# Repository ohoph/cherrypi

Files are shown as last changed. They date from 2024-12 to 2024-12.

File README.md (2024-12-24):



# cherrypi

Raspberry Pi Zero 2 W based Portable Chess Computer





# Cherrypi - über Kirschkuchen und Schachcomputer

Dieses Repository dokumentiert den Aufbau meines selbstgebauten Schachcomputers – ein persönliches Projekt, das von der Idee bis zur Umsetzung eine Reise voller Höhen und Tiefen war. Der Computer sollte ein Weihnachtsgeschenk sein, das nicht nur funktional, sondern auch emotional besonders ist. Obwohl er heute nicht funktionsfähig ist, bedeutet mir dieses Projekt eine Menge. Es war eine Reise mit vielen Höhen und Tiefen, ich habe sooo viel gelernt und hoffe darauf, dass dieses Projekt eines Tages (bald) von allen nachgebaut werden kann, die sich ein ähnliches Projekt wünschen. 

IMG_8A8BB41F64B1-1

---

## 🛠️ **Funktionalität**

Der Cherrypi-Schachcomputer bietet:

1. **Eigenständige Schachfunktion:**
   - Nutzt **Stockfish** als Schach-Engine. Spielt auf etwa 2500er ELO. 
   - Steuere das Spiel mit einer 16-Tasten-Matrix (ähnlich einem tragbaren Brett).
   - Zeigt Spielinformationen auf einem **OLED-Display** an.

2. **Portabilität:**
   - Dank eines **UPS-Moduls** (mit Akku) und eines **Ein/Aus-Schiebeschalters** kann der Computer überall verwendet werden.

3. **Software-Integration:**
   - Automatischer Start in das Schachprogramm direkt beim Hochfahren.
   - Alle Funktionen laufen eigenständig – ohne Internetverbindung.

4. **Benutzerfreundliches Gehäuse:**
   - Ein 3D-gedrucktes Gehäuse schützt die Hardware.
   - Magnetverschluss für einfachen Zugriff auf die Elektronik.
   - 3D-gedruckte Keycaps für ein individuelles Schach-Feeling.

---
## 🎮 **Spielanleitung**

### **Tastenbelegung**
Die 16-Tasten-Matrix ist wie folgt organisiert:

| Taste (S1-S16) | Funktionalität | Beschreibung |
|---|---|---|
| S1 | A/1 | Spalte A oder Reihe 1 |
| S2 | B/2 | Spalte A oder Reihe 1 |
| S3 | C/3 | Spalte A oder Reihe 1 |
| S4 | D/4 | Spalte A oder Reihe 1 |
| S5 | E/5 | Spalte A oder Reihe 1 |
| S6 | F/6 | Spalte A oder Reihe 1 |
| S7 | G/7 | Spalte A oder Reihe 1 |
| S8 | H/8 | Spalte A oder Reihe 1 |
| S9 | Dame | Bauernumwandlung in Dame |
| S10 | Turm | Bauernumwandlung in Turm |
| S11 | Läufer | Bauernumwandlung in Läufer |
| S12 | Springer | Bauernumwandlung in Springer |
| S13 | Surrender | Beendet Spiel durch Aufgabe |
| S14 | Clear | Löscht gesamte Eingabe |
| S15 | Delete | Löscht letzte Ziffer von Eingabe |
| S16 | Go | Bestätigt Eingabe |

### **Züge eingeben**
- Um einen Zug einzugeben, drücke **nacheinander zwei Felder**:
  - Das erste Feld ist die Startposition des Steins.
  - Das zweite Feld ist die Zielposition des Steins.
  - Beispiel: Um von `E2` nach `E4` zu ziehen, drücke die Tasten 5,2,5,4 (e2e4) und bestätige den Zug mit "Go". 

### **Sonderfunktionen**
- **Bauernumwandlung:**
  - Wird ein Bauer in die letzte Reihe bewegt, erscheint auf dem Display die Aufforderung zur Umwandlung.
  - Wähle mit den Tasten `9`, `10`, `11`, `12` die gewünschte Figur:
    - `9`: Königin
    - `10`: Turm
    - `11`: Läufer
    - `12`: Springer

- **Rochade:**
  - Gib den Zug des Königs an. Das System erkennt automatisch die Rochade, sofern legal.

- **Zug zurücknehmen:**
  - Halte die Taste `14` gedrückt, um den letzten Zug zurückzunehmen.

- **Neues Spiel starten:**
  - Halte `13` gedrückt, um aufzugeben und eine neue Partie zu beginnen.

### **Display-Anzeige**

- Das OLED-Display zeigt:
  - Den aktuellen Zug.
  - Die letzten Züge.
  - Hinweise wie "Press any key to start" oder Fehler bei illegalen Zügen.

## 🔧 **Zusammenbau**

### **Benötigte Komponenten**
- **Raspberry Pi Zero W** (ohne Headerpins).
- **1,3-Zoll-OLED-Display** (I2C, 128x64 Pixel).
- **16-Tasten-Matrix**.
- **3D-gedrucktes Gehäuse** (STLs sind in diesem Repository verfügbar!).
- **3D-gedruckte Keycaps für die Tasten-Matrix** (Wird diesem Repository als STL beigefügt, sobald die finalen Designs fertig sind)
- **Magnete** für den Verschlussmechanismus.
- **Lötstation**, Lötzinn, Entlötpumpe und Multimeter.

### **Software**
- Raspberry Pi OS Lite (32-Bit).
- Python-Skripte für das Schachprogramm, das OLED-Display und die Tastatureingabe.
- Systemd-Dienste für das automatische Starten von Programmen und das Überwachen des UPS-Schalters.

---

## 💡 **Schritte zum Zusammenbau**

### **1. Hardware vorbereiten**
- **OLED-Display:** I2C-Verbindungen verlöten und testen.
- **Tastaturmatrix:** Verlöten und mit GPIO-Pins verbinden.
- **Raspberry Pi:** Headerpins entfernen (falls vorhanden) und alle Verbindungen sauber verlöten.
- **UPS-Modul:** Mit dem Pi verbinden und den Schalter für Ein/Aus konfigurieren.

### 2. Softwareanforderungen
1. **Raspberry Pi OS** (aktuellste Version)
2. **Python 3**
3. Bibliotheken:
   - `RPi.GPIO`
   - `luma.oled`
   - `Pillow`
   - `python-chess`
   - `stockfish`
4. **I2C-Tools** zur Aktivierung und Testen des I2C-Busses.

### Hardware und Komponentenliste
| **Komponente** | **Anzahl** | **Beschreibung** |
|---|---|---|
| Raspberry Pi Zero 2 W | 1 | Mini-Computer zur Steuerung |
| 1.3 Zoll OLED Display (SH1106, I2C) | 1 | Display zur Anzeige der Schachzüge |
| 4x4 Button-Matrix | 1 | Eingabegerät für Schachzüge |
| LiPo-Akku 3.7V (1000mAh) | 1 | Stromversorgung für den Raspberry Pi |
| Waveshare UPS HAT für Raspberry Pi Zero | 1 | HAT-Modul zur Akkuverwaltung und Stromversorgung|
| Micro-SD-Karte (mind. 8GB) | 1 | Speicherkarte für Raspberry Pi OS und Code |

---

## Wiring Guide 

Bildschirmfoto 2024-12-16 um 10 53 50

### Button-Matrix Verkabelung
| **Matrix-Pin** | **Raspberry Pi GPIO (BCM)** | **Physischer Pin** | **Beschreibung** |
|---|---|---|---|
| **1** | GPIO 25 | Pin 22 | Zeile 1 |
| **2** | GPIO 23 | Pin 16 | Zeile 2 |
| **3** | GPIO 24 | Pin 18 | Zeile 3 |
| **4** | GPIO 18 | Pin 12 | Zeile 4 |
| **5** | GPIO 27 | Pin 13 | Spalte 1 |
| **6** | GPIO 22 | Pin 15 | Spalte 2 |
| **7** | GPIO 17 | Pin 11 | Spalte 3 |
| **8** | GPIO 4 | Pin 7 | Spalte 4 |

### OLED-Display (SH1106) Verkabelung
| **OLED Pin** | **Raspberry Pi GPIO (BCM)** | **Physischer Pin** | **Beschreibung** |
|---|---|---|---|
| **VCC** | 3.3V | Pin 1 | Spannungsversorgung |
| **GND** | GND | Pin 9 | Masse |
| **SDA** | GPIO 2 (SDA) | Pin 3 | I2C-Datenleitung |
| **SCL** | GPIO 3 (SCL) | Pin 5 | I2C-Taktleitung | 

### Zusammenfassung der Pinbelegung
| **Funktion** | **Raspberry Pi GPIO (BCM)** | **Physischer Pin** |
|---|---|---|
| Button-Matrix Zeile 1 | GPIO 25 | Pin 22 |
| Button-Matrix Zeile 2 | GPIO 23 | Pin 16 |
| Button-Matrix Zeile 3 | GPIO 24 | Pin 18 |
| Button-Matrix Zeile 4 | GPIO 18 | Pin 12 |
| Button-Matrix Spalte 1| GPIO 27 | Pin 13 |
| Button-Matrix Spalte 2| GPIO 22 | Pin 15 |
| Button-Matrix Spalte 3| GPIO 17 | Pin 11 |
| Button-Matrix Spalte 4| GPIO 4 | Pin 7 |
| OLED VCC | 3.3V | Pin 1 |
| OLED GND | GND | Pin 9 |
| OLED SDA | GPIO 2 (SDA) | Pin 3 |
| OLED SCL | GPIO 3 (SCL) | Pin 5 |

### Hinweise für die Verkabelung
1. **Button-Matrix**: Die Reihen-Pins sind als **Eingänge** und die Spalten-Pins als **Ausgänge** konfiguriert.
2. **OLED-Display**: Verwendet das **I2C-Protokoll**; muss in der Raspberry Pi Konfiguration aktiviert entsprechend werden (`sudo raspi-config`).

### Bildergalerie



IMG_86837E7B299C-1

https://github.com/user-attachments/assets/6dfa8066-77cf-47a0-b1ef-a18c7b4af382

---

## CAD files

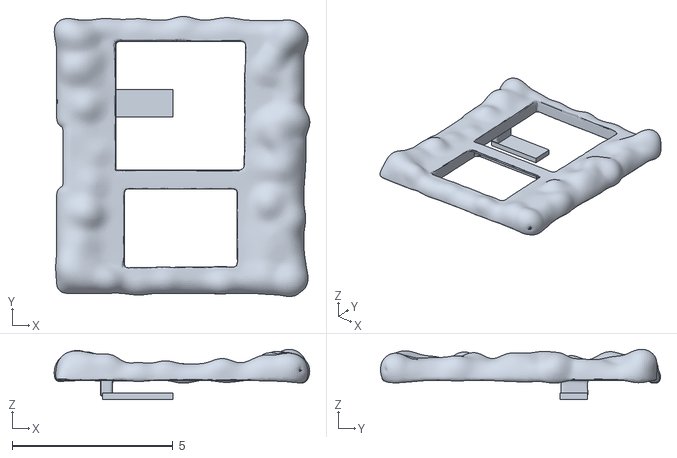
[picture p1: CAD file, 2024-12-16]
STLs/chesspbry_finalv1_top.stl
7.94 x 8.70 x 1.56

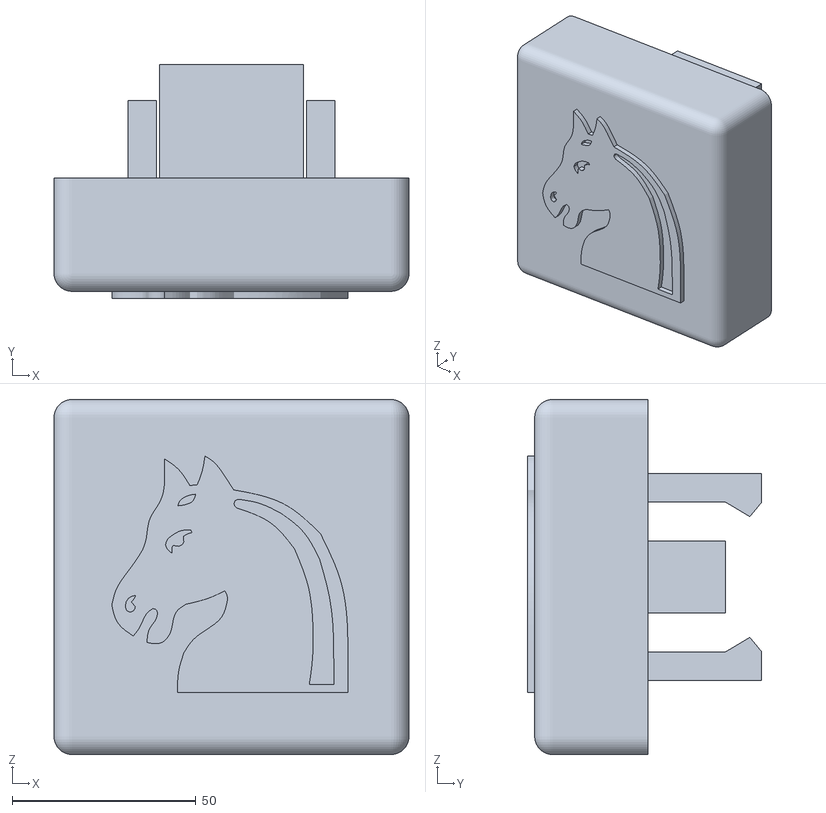
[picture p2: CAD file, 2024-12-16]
STLs/Keycap STLs/Springer-cap.stl
96.5 x 63.7 x 96.5

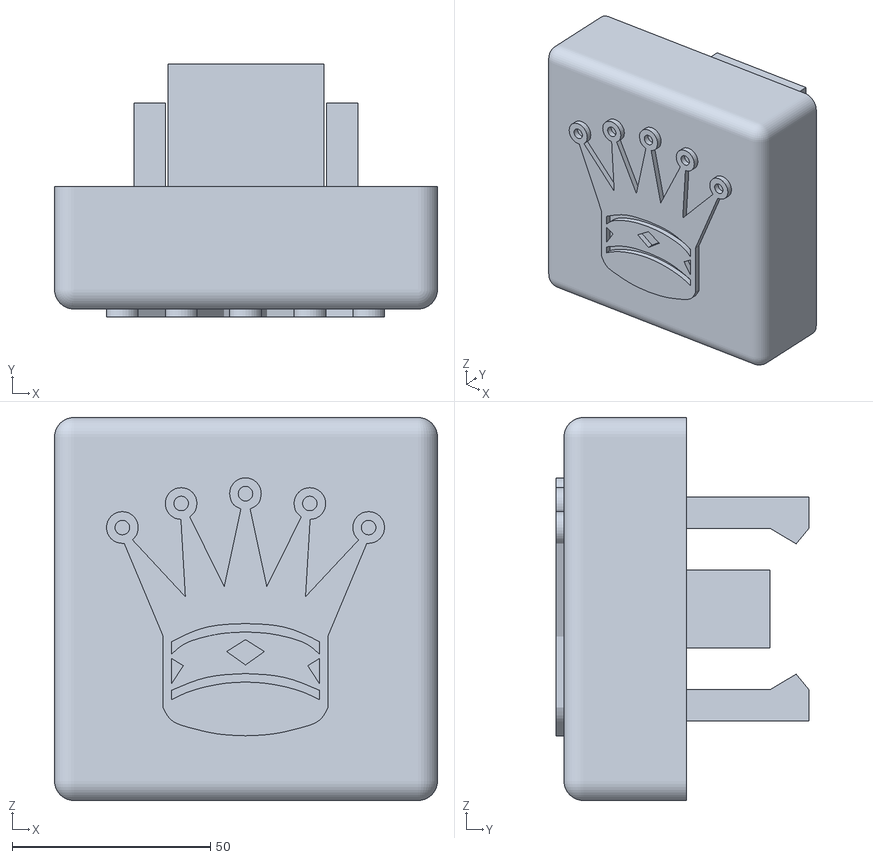
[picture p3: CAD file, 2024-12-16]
STLs/Keycap STLs/Königin.stl
96.5 x 63.7 x 96.5

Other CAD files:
STLs/Keycap STLs/Läufer-Cap.stl
STLs/Keycap STLs/Turm-cap.stl
STLs/Keycap STLs/B2-cap.stl
STLs/Keycap STLs/Go-cap.stl
STLs/Keycap STLs/C3-cap.stl
STLs/Keycap STLs/F6-cap.stl
STLs/Keycap STLs/G7-cap.stl
STLs/Keycap STLs/Correct-cap.stl
STLs/Keycap STLs/König-cap.stl
STLs/Keycap STLs/Cancel-cap.stl
STLs/Keycap STLs/A1-cap.stl
STLs/Keycap STLs/E5-cap.stl
STLs/Keycap STLs/H8-cap.stl
STLs/Keycap STLs/D4-cap.stl

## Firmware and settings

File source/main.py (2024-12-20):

import random
import RPi.GPIO as GPIO
import time
import chess
import chess.engine
from luma.core.interface.serial import i2c
from luma.oled.device import sh1106
from PIL import ImageDraw, ImageFont, Image


# GPIO-Setup für Buttons
class ButtonMatrix:
    def __init__(self):
        GPIO.setmode(GPIO.BCM)
        GPIO.setwarnings(False)
        self.buttonIDs = [[4, 3, 2, 1], [8, 7, 6, 5], [16, 15, 14, 13], [12, 11, 10, 9]]
        self.rowPins = [18, 23, 24, 25]
        self.columnPins = [21, 22, 17, 4]
        for row in self.rowPins:
            GPIO.setup(row, GPIO.IN, pull_up_down=GPIO.PUD_UP)
        for col in self.columnPins:
            GPIO.setup(col, GPIO.OUT)
            GPIO.output(col, GPIO.HIGH)

    def readButton(self):
        for j, colPin in enumerate(self.columnPins):
            GPIO.output(colPin, GPIO.LOW)  # Aktiviere Spalte
            for i, rowPin in enumerate(self.rowPins):
                if GPIO.input(rowPin) == GPIO.LOW:  # Wenn Zeile aktiviert wird
                    GPIO.output(colPin, GPIO.HIGH)  # Spalte deaktivieren
                    time.sleep(0.2)  # Debounce
                    return i, j  # Rückgabe von Zeile und Spalte
            GPIO.output(colPin, GPIO.HIGH)  # Spalte deaktivieren
        return None


# OLED-Setup
class OLED:
    def __init__(self):
        serial = i2c(port=1, address=0x3C)
        self.device = sh1106(serial)
        self.font = ImageFont.load_default()

    def display_text(self, text):
        with Image.new("1", (self.device.width, self.device.height)) as image:
            draw = ImageDraw.Draw(image)
            draw.text((0, 0), text, font=self.font, fill=255)
            self.device.display(image)

    def clear(self):
        self.device.clear()

    def display_logo(self):
        logo_image = Image.new("1", (128, 64))
        logo_pixels = logo_image.load()

        # Logo-Daten
        logo_data = [
            0x00, 0x00, 0x00, 0x00, 0x00, 0x00, 0x00, 0x00, 0x00, 0x00, 0x00, 0x00, 0x00, 0x00, 0x00, 0x00,
            0x00, 0x00, 0x00, 0x00, 0x00, 0x00, 0x00, 0x00, 0x00, 0x00, 0x00, 0x00, 0x00, 0x00, 0x00, 0x00,
            0x00, 0x00, 0x00, 0x00, 0x00, 0x00, 0x00, 0x00, 0x00, 0x00, 0x00, 0x00, 0x00, 0x00, 0x00, 0x00,
            0x00, 0x00, 0x00, 0x00, 0x00, 0x00, 0x00, 0x00, 0x00, 0x00, 0x00, 0x00, 0x00, 0x00, 0x00, 0x00,
            0x00, 0x00, 0x00, 0x00, 0x00, 0x00, 0x00, 0x00, 0x00, 0x00, 0x00, 0x00, 0x00, 0x00, 0x00, 0x00,
            0x00, 0x00, 0x00, 0x00, 0x00, 0x00, 0x00, 0x00, 0x00, 0x00, 0x00, 0x00, 0x00, 0x00, 0x00, 0x00,
            0x00, 0x00, 0x00, 0x00, 0x00, 0x00, 0x00, 0x00, 0x00, 0x00, 0x00, 0x00, 0x00, 0x00, 0x00, 0x00,
            0x00, 0x00, 0x00, 0x00, 0x00, 0x00, 0x00, 0x00, 0x00, 0x00, 0x00, 0x00, 0x00, 0x00, 0x00, 0x00,
            0x00, 0x00, 0x00, 0x00, 0x00, 0x00, 0x00, 0x00, 0x00, 0x00, 0x00, 0x00, 0x00, 0x00, 0x00, 0x00,
            0x00, 0x00, 0x00, 0x00, 0x00, 0x00, 0x00, 0x00, 0x00, 0x00, 0x00, 0x00, 0x00, 0x00, 0x00, 0x00,
            0x00, 0x00, 0x00, 0x00, 0x00, 0x00, 0x00, 0x00, 0x00, 0x00, 0x00, 0x00, 0x00, 0x00, 0x00, 0x00,
            0x00, 0x00, 0x00, 0x00, 0x00, 0x00, 0x00, 0x00, 0x00, 0x0e, 0x00, 0x00, 0x00, 0x00, 0x00, 0x00,
            0x00, 0x00, 0x00, 0x00, 0x00, 0x00, 0xe0, 0x00, 0x00, 0x1e, 0x00, 0x00, 0x00, 0x00, 0x00, 0x00,
            0x00, 0x00, 0x00, 0x00, 0x00, 0x00, 0xe0, 0x00, 0x00, 0x1e, 0x00, 0x00, 0x00, 0x00, 0x00, 0x00,
            0x00, 0x00, 0x00, 0x00, 0x00, 0x00, 0xf0, 0x00, 0x00, 0x1e, 0x00, 0x00, 0x00, 0x00, 0x00, 0x00,
            0x00, 0x00, 0x00, 0x00, 0x00, 0x00, 0xf0, 0x01, 0x80, 0x1e, 0x00, 0x00, 0x00, 0x00, 0x00, 0x00,
            0x00, 0x00, 0x00, 0x00, 0x00, 0x00, 0xf0, 0x03, 0x80, 0x1e, 0x00, 0x00, 0x00, 0x00, 0x00, 0x00,
            0x00, 0x00, 0x00, 0x00, 0x00, 0x00, 0xf0, 0x03, 0xc0, 0x1e, 0x00, 0x00, 0x00, 0x00, 0x00, 0x00,
            0x00, 0x00, 0x00, 0x00, 0x00, 0x00, 0xf0, 0x03, 0xc0, 0x1e, 0x00, 0x00, 0x00, 0x00, 0x00, 0x00,
            0x00, 0x00, 0x00, 0x00, 0x00, 0x00, 0xf0, 0x03, 0xc0, 0x1e, 0x00, 0x00, 0x00, 0x00, 0x00, 0x00,
            0x00, 0x00, 0x00, 0x00, 0x00, 0x01, 0xf0, 0x03, 0xc0, 0x1e, 0x00, 0x00, 0x00, 0x00, 0x00, 0x00,
            0x00, 0x00, 0x00, 0x00, 0x00, 0x01, 0xf8, 0x07, 0xe0, 0x3f, 0x00, 0x00, 0x00, 0x00, 0x00, 0x00,
            0x00, 0x00, 0x00, 0x00, 0x00, 0xff, 0xff, 0xff, 0xff, 0xff, 0xfc, 0x00, 0x00, 0x00, 0x00, 0x00,
            0x00, 0x00, 0x00, 0x00, 0x07, 0xff, 0xff, 0xff, 0xff, 0xff, 0xff, 0xc0, 0x00, 0x00, 0x00, 0x00,
            0x00, 0x00, 0x00, 0x00, 0x1f, 0xf8, 0x00, 0x00, 0x00, 0x1f, 0xff, 0xe0, 0x00, 0x00, 0x00, 0x00,
            0x00, 0x00, 0x00, 0x00, 0x3f, 0x80, 0x00, 0x00, 0x00, 0x00, 0x00, 0x00, 0x00, 0x00, 0x00, 0x00,
            0x00, 0x00, 0x00, 0x00, 0x3e, 0x00, 0x00, 0x00, 0x00, 0x00, 0x00, 0x00, 0x00, 0x00, 0x00, 0x00,
            0x00, 0x00, 0x00, 0x00, 0x3e, 0x00, 0x00, 0x00, 0x00, 0x00, 0x00, 0x00, 0x00, 0x00, 0x00, 0x00,
            0x00, 0x00, 0x00, 0x00, 0x3e, 0x00, 0x00, 0x00, 0x00, 0x00, 0x00, 0x00, 0x00, 0x00, 0x00, 0x00,
            0x00, 0x00, 0x00, 0x00, 0x1f, 0x80, 0x00, 0x00, 0x00, 0x00, 0x00, 0x00, 0x00, 0x00, 0x00, 0x00,
            0x00, 0x00, 0x00, 0x00, 0x1f, 0xff, 0x00, 0x00, 0x00, 0x00, 0x00, 0x00, 0x00, 0x00, 0x00, 0x00,
            0x00, 0x00, 0x00, 0x00, 0x3f, 0xff, 0xff, 0xff, 0xff, 0xff, 0xf8, 0x00, 0x00, 0x00, 0x00, 0x00,
            0x00, 0x00, 0x00, 0x00, 0x7f, 0xff, 0xff, 0xff, 0xff, 0xff, 0xff, 0xe0, 0x00, 0x00, 0x00, 0x00,
            0x00, 0x00, 0x00, 0x00, 0xfc, 0x0f, 0xfe, 0x00, 0x01, 0xff, 0xff, 0xfc, 0x00, 0x00, 0x00, 0x00,
            0x00, 0x00, 0x00, 0x00, 0xf0, 0x07, 0xfe, 0x00, 0x00, 0x7f, 0x00, 0x7f, 0x00, 0x00, 0x00, 0x00,
            0x00, 0x00, 0x00, 0x01, 0xe0, 0x03, 0xff, 0x80, 0x00, 0x7e, 0x00, 0x1f, 0x80, 0x00, 0x00, 0x00,
            0x00, 0x00, 0x00, 0x01, 0xe0, 0x03, 0xe7, 0xe0, 0x00, 0x3e, 0x00, 0x07, 0xc0, 0x00, 0x00, 0x00,
            0x00, 0x00, 0x00, 0x01, 0xe0, 0x03, 0xc1, 0xfc, 0x00, 0x3e, 0x00, 0x03, 0xc0, 0x00, 0x00, 0x00,
            0x00, 0x00, 0x00, 0x01, 0xe0, 0x03, 0x80, 0x7f, 0x00, 0x3e, 0x00, 0x07, 0x80, 0x00, 0x00, 0x00,
            0x00, 0x00, 0x00, 0x01, 0xf0, 0x03, 0x80, 0x1f, 0xe0, 0x3e, 0x00, 0x0f, 0x00, 0x00, 0x00, 0x00,
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
        ]

        # Logo-Daten rendern
        for y in range(64):
            for x in range(128):
                byte_index = (y * 128 + x) // 8
                bit_index = 7 - (x % 8)
                if logo_data[byte_index] & (1 << bit_index):
                    logo_pixels[x, y] = 1

        self.device.display(logo_image)



# Schachcomputer-Logik und Interaktion
class ChessComputer:
    def __init__(self):
        self.matrix = ButtonMatrix()
        self.oled = OLED()
        self.board = chess.Board()
        self.engine = chess.engine.SimpleEngine.popen_uci("/usr/games/stockfish", timeout=10)

        # Konfiguration des Stockfish-Skill-Levels
        self.engine.configure({
            "Skill Level": 20,  # Maximales Level
            "Threads": 4        # Multi-Threading für schnellere Berechnungen
        })

        self.current_move = ""
        self.phase = 0
        self.log = []  # Für Anzeige der letzten Züge
        self.computer_turn = None
        self.start_game()

    def start_game(self):
        self.display_startup_animation()
        self.display_start_prompt()
        self.determine_starting_player()

    def display_startup_animation(self):
        self.oled.display_logo()
        time.sleep(2)  # Zeige das Logo 3 Sekunden lang an
        self.oled.clear()

    def display_start_prompt(self):
        self.oled.display_text("Press any key\nto start")
        while not self.matrix.readButton():
            time.sleep(0.1)
        self.oled.clear()

    def determine_starting_player(self):
        self.computer_turn = random.choice([True, False])
        if self.computer_turn:
            self.oled.display_text("Computer starts.")
            time.sleep(2)
            self.computer_move()
        else:
            self.oled.display_text("Player starts.\nenter first move:")
            time.sleep(2)

    def display_game_status(self, current_message=None):
        # Füge aktuelle Nachricht hinzu, falls vorhanden
        if current_message:
            if not self.log or self.log[-1] != current_message:  # Verhindere doppelte Logs
                self.log.append(current_message)

        # Baue die Anzeige auf
        text = "\n".join(self.log[-3:])  # Zeige die letzten 3 Züge
        if self.computer_turn:
            text += "\nComputer thinks..."
        elif self.current_move:
            text += f"\nInput move: {self.current_move}"
        else:
            text += "\nInput move:"

        self.oled.display_text(text)


    def handle_input(self):
        if self.computer_turn:
            return  # Spieler kann keine Eingaben machen, wenn der Computer zieht

        button = self.matrix.readButton()
        if button:
            row, col = button
            button_id = self.matrix.buttonIDs[row][col]
            self.process_input(button_id)

    def process_input(self, button_id):
        # Sondertasten
        if button_id == 13:  # Aufgeben
            self.oled.display_text("Confirm surrender?")
            while True:
                button = self.matrix.readButton()
                if button:
                    row, col = button
                    confirm_id = self.matrix.buttonIDs[row][col]
                    if confirm_id == 16:  # GO-Taste
                        self.oled.display_text("Game over.\nPlayer surrendered.")
                        self.end_game()
                        return
                    else:
                        self.oled.display_text("Cancelled.")
                        time.sleep(1)
                        self.display_game_status()
                        return

        elif button_id == 14:  # Clear
            self.current_move = ""
            self.phase = 0
            self.display_game_status()
            return

        elif button_id == 15:  # Del
            if self.current_move:
                # Entferne das letzte Zeichen
                self.current_move = self.current_move[:-1]
                # Setze die Phase entsprechend der verbleibenden Eingabe zurück
                if len(self.current_move) == 0:
                    self.phase = 0  # Kein Zeichen: Zurück zur Spalteneingabe
                elif len(self.current_move) == 1:
                    self.phase = 1  # Ein Zeichen: In der Zeileneingabe des Startfelds
                elif len(self.current_move) == 2:
                    self.phase = 2  # Zwei Zeichen: Spalteneingabe des Zielfelds
                elif len(self.current_move) == 3:
                    self.phase = 3  # Drei Zeichen: Zeileneingabe des Zielfelds
                self.display_game_status()  # Zeige aktualisierte Eingabe an
            else:
                self.oled.display_text("Nothing to delete.")
                time.sleep(1)
            return

        elif button_id == 16:  # GO
            if len(self.current_move) == 4:  # Normale Züge
                if self.check_promotion():
                    self.oled.display_text("Choose piece to\nconvert to.")
                    return  # Warte auf Umwandlungseingabe
                if self.make_move(self.current_move):
                    self.current_move = ""  # Zug zurücksetzen
                    self.phase = 0
                    self.computer_turn = True
                    self.display_game_status()
                else:
                    self.oled.display_text("Invalid move.")
                    time.sleep(1)
                    self.current_move = ""
                    self.phase = 0
                    self.display_game_status()  # Aktualisiere den Status nach Fehler
            elif len(self.current_move) == 5:  # Umwandlungszüge (mit Figur)
                if self.make_move(self.current_move):
                    self.current_move = ""  # Zug zurücksetzen
                    self.phase = 0
                    self.computer_turn = True
                    self.display_game_status()
                else:
                    self.oled.display_text("Invalid move.")
                    time.sleep(1)
                    self.current_move = ""
                    self.phase = 0
                    self.display_game_status()  # Aktualisiere den Status nach Fehler
            else:
                self.oled.display_text("Move not complete.")
                time.sleep(1)
                self.display_game_status()  # Aktualisiere den Status nach Fehler
            return



        # Umwandlungstasten
        elif button_id in [9, 10, 11, 12]:  # Umwandlung (Dame, Turm, Läufer, Springer)
            promotion_pieces = {9: "q", 10: "r", 11: "b", 12: "n"}
            if self.phase == 3 and self.current_move:
                self.current_move += promotion_pieces[button_id]
                self.display_game_status(f"Selected: {promotion_pieces[button_id]}")
            else:
                self.oled.display_text("No conversion\npossible.")
                time.sleep(1)
            return

        # Normale Eingabe
        if self.phase == 0:  # Startfeld Spalte (a-h)
            if 1 <= button_id <= 8:
                self.current_move = chr(96 + button_id)
                self.phase = 1
                self.display_game_status()
            else:
                self.oled.display_text("Invalid move.\nFrom-Column.")
                time.sleep(1)
                self.display_game_status()
        elif self.phase == 1:  # Startfeld Zeile (1-8)
            if 1 <= button_id <= 8:
                self.current_move += str(button_id)
                self.phase = 2
                self.display_game_status()
            else:
                self.oled.display_text("Invalid move.\nFrom-Row.")
                time.sleep(1)
                self.display_game_status()
        elif self.phase == 2:  # Zielfeld Spalte (a-h)
            if 1 <= button_id <= 8:
                self.current_move += chr(96 + button_id)
                self.phase = 3
                self.display_game_status()
            else:
                self.oled.display_text("Invalid move.\nTo-Column.")
                time.sleep(1)
                self.display_game_status()
        elif self.phase == 3:  # Zielfeld Zeile (1-8)
            if 1 <= button_id <= 8:
                self.current_move += str(button_id)
                self.display_game_status()
            else:
                self.oled.display_text("Invalid move.\nTo-Row.")
                time.sleep(1)
                self.display_game_status()

    def check_promotion(self):
        try:
            # Überprüfe, ob der aktuelle Zug gültig ist
            if not self.current_move or len(self.current_move) < 4:
                return False

            last_move = chess.Move.from_uci(self.current_move.lower())
            piece = self.board.piece_at(last_move.from_square)
            
            # Prüfen, ob ein Bauer auf dem Feld ist und ob er auf eine Umwandlungsreihe zieht
            if piece and piece.symbol().lower() == "p" and chess.square_rank(last_move.to_square) in [0, 7]:
                return True

            return False
        except Exception as e:
            print(f"Fehler in check_promotion: {e}")
            return False


    def make_move(self, move):
        try:
            chess_move = chess.Move.from_uci(move.lower())
            if chess_move in self.board.legal_moves:
                self.board.push(chess_move)  # Spielerzug ausführen
                self.log.append(f"Player: {move}")  # Zug protokollieren
                self.current_move = ""  # Eingabe zurücksetzen
                self.phase = 0  # Phase zurücksetzen
                if not self.board.is_game_over():
                    self.computer_move()  # Computerzug ausführen
                return True
        except ValueError:
            pass
        return False

    def computer_move(self):
        try:
            if not self.computer_turn:  # Verhindere Doppelzug
                return

            result = self.engine.play(self.board, chess.engine.Limit(time=2))
            self.board.push(result.move)
            
            # Log und Anzeige aktualisieren
            move_text = f"Computer: {result.move.uci()}"
            if self.log and self.log[-1] != move_text:  # Verhindere doppelte Logs
                self.log.append(move_text)
            self.display_game_status(move_text)
        except Exception as e:
            print(f"Fehler beim Computerzug: {e}")
            self.oled.display_text("Error with\n Computer move!")
            time.sleep(2)
        finally:
            self.computer_turn = False  # Übergibt die Kontrolle an den Spieler
            self.display_game_status()  # Aktualisiere das Display für den Spieler




    def end_game(self):
        self.oled.display_text("Game over.\nWanna go\nagain?")
        
        while True:
            button = self.matrix.readButton()
            if button:
                row, col = button
                button_id = self.matrix.buttonIDs[row][col]
                if button_id == 16:  # GO-Taste
                    # Schachbrett und Status zurücksetzen
                    self.board.reset()
                    self.phase = 0
                    self.current_move = ""
                    self.computer_turn = None
                    self.log = []  # Spiel-Log zurücksetzen
                    self.display_start_prompt()  # Prompt für neues Spiel anzeigen
                    self.determine_starting_player()  # Wer startet, erneut bestimmen
                    return  # Kehre zur Hauptspiel-Schleife zurück
                else:
                    self.oled.display_text("Confirm\nto start over.")
                    time.sleep(1)


    def run(self):
        while not self.board.is_game_over():
            if self.computer_turn:
                self.computer_move()
            else:
                self.handle_input()
            time.sleep(0.1)  # CPU-Last reduzieren

        self.end_game()


if __name__ == "__main__":
    chess_computer = ChessComputer()
    chess_computer.run()

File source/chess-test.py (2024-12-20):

import chess
import chess.engine
import time
from luma.core.interface.serial import i2c
from luma.oled.device import sh1106
from PIL import ImageDraw, ImageFont, Image


class OLED:
    def __init__(self):
        serial = i2c(port=1, address=0x3C)
        self.device = sh1106(serial)
        self.font = ImageFont.load_default()

    def display_text(self, text):
        with Image.new("1", (self.device.width, self.device.height)) as image:
            draw = ImageDraw.Draw(image)
            draw.text((0, 0), text, font=self.font, fill=255)
            self.device.display(image)

    def clear(self):
        self.device.clear()


class TestChessLogicWithStockfish:
    def __init__(self, stockfish_path):
        self.board = chess.Board()
        self.engine_test = chess.engine.SimpleEngine.popen_uci(stockfish_path)
        self.engine_chess_computer = chess.engine.SimpleEngine.popen_uci(stockfish_path)
        self.move_count = 0
        self.oled = OLED()
        self.log = []  # Log der letzten Züge für die OLED-Anzeige

    def display_game_status(self, current_message=None):
        # Füge aktuelle Nachricht hinzu, falls vorhanden
        if current_message:
            if not self.log or self.log[-1] != current_message:  # Verhindere doppelte Logs
                self.log.append(current_message)

        # Baue die Anzeige auf
        text = "\n".join(self.log[-3:])  # Zeige die letzten 3 Züge
        if self.board.turn:
            text += "\nDein Zug:"
        else:
            text += "\nWarten auf Computer..."

        self.oled.display_text(text)

    def simulate_game(self, max_moves=200, delay=2):
        self.oled.display_text("Simulation startet...")
        time.sleep(2)

        while not self.board.is_game_over() and self.move_count < max_moves:
            self.oled.clear()
            print(f"\n--- Zug {self.move_count + 1} ---")
            print(self.board)

            # Entscheide, wer zieht
            if self.board.turn:
                # Weiß zieht (Test-Computer, als "Spieler")
                result = self.engine_test.play(self.board, chess.engine.Limit(time=1))
                move = result.move
                player = "Spieler (Weiß)"
            else:
                # Schwarz zieht (Schachcomputer, als "Computer")
                result = self.engine_chess_computer.play(self.board, chess.engine.Limit(time=1))
                move = result.move
                player = "Computer (Schwarz)"

            # Ausgabe des Zugs
            print(f"{player} zieht: {move}")
            if self.is_promotion(move):
                print(f"Umwandlung erfolgreich: {move}")

            # Aktualisiere OLED
            if player.startswith("Spieler"):
                log_message = f"Spieler: {move}"
            else:
                log_message = f"Computer: {move}"
            self.display_game_status(log_message)

            # Zug ausführen
            self.board.push(move)
            self.move_count += 1
            time.sleep(delay)

        self.oled.clear()
        self.oled.display_text("Spiel beendet!")

        print("\n=== Spiel beendet ===")
        if self.board.is_checkmate():
            print("Schachmatt! Gewinner:", "Weiß" if self.board.turn else "Schwarz")
        elif self.board.is_stalemate():
            print("Patt! Keine weiteren Züge möglich.")
        elif self.board.is_insufficient_material():
            print("Unentschieden wegen unzureichendem Material.")
        else:
            print("Maximale Züge erreicht.")

        print("\nEndstand des Schachbretts:")
        print(self.board)

    def is_promotion(self, move):
        piece = self.board.piece_at(move.from_square)
        if piece and piece.piece_type == chess.PAWN and chess.square_rank(move.to_square) in [0, 7]:
            return True
        return False

    def run(self):
        try:
            self.simulate_game(max_moves=200, delay=1)
        except Exception as e:
            print(f"Fehler während der Simulation: {e}")
        finally:
            self.engine_test.quit()
            self.engine_chess_computer.quit()


if __name__ == "__main__":
    stockfish_path = "/usr/games/stockfish"
    test_chess_logic = TestChessLogicWithStockfish(stockfish_path)
    test_chess_logic.run()
